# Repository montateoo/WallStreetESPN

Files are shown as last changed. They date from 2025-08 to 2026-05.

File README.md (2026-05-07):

# WallStreetESPN

A compact, self-contained stock market display built on the ESP8266. It fetches real-time prices from the Finnhub API, cycles through your personal portfolio on a 128x64 OLED, and runs a paper trading algorithm in the background — all manageable from a built-in web interface.

---

## Features

- Real-time stock quotes (Finnhub API, free tier)
- Smooth horizontal slide animations between stocks
- Market countdown — shows time until NYSE opens or closes
- Paper trading — SMA(3)/SMA(7) crossover algorithm with $100 virtual budget
- Built-in web UI — add/remove stocks, configure settings, view trading dashboard
- PWM-controlled LED brightness (green = price up / red = price down)
- Persistent storage — portfolio, API key, settings and trading state survive reboots
- NTP time sync (CET/CEST automatic)

---

## Hardware

| Component | Details |
|---|---|
| Microcontroller | ESP8266 (NodeMCU / Wemos D1 Mini) |
| Display | 128x64 OLED I2C (SSD1306, address 0x3C) |
| Green LED | GPIO 13 (D7) + 220Ω resistor |
| Red LED | GPIO 15 (D8) + 220Ω resistor |
| Button — Mode | GPIO 14 (D5) + 10kΩ pull-down |
| Button — WiFi Reset | GPIO 12 (D6) + 10kΩ pull-down |
| I2C SDA | GPIO 4 (D2) |
| I2C SCL | GPIO 5 (D1) |
| Power | USB-C 4.5–9V module |

See `Schematic_wallStreetDisplay_2025-08-30.pdf` for the full circuit diagram.  
3D-printable enclosure parts are in `3DprintComponents/`.

---

## Software Dependencies

Install all of these through **Arduino IDE → Sketch → Include Library → Manage Libraries**:

| Library | Author |
|---|---|
| ArduinoJson | Benoit Blanchon |
| WiFiManager | tzapu |
| Adafruit SSD1306 | Adafruit |
| Adafruit GFX Library | Adafruit |

Board package (via Boards Manager):  
`https://arduino.esp8266.com/stable/package_esp8266com_index.json`  
→ Install **esp8266 by ESP8266 Community**

---

## Setup

### 1. Get a Finnhub API key
Sign up for free at [finnhub.io](https://finnhub.io) and copy your API key.

### 2. Flash the firmware
- Open `code.ino` in Arduino IDE
- Select **Tools → Board → ESP8266 Boards → NodeMCU 1.0**
- Select the correct **Tools → Port** (use Device Manager to find it)
- Upload speed: 115200
- Serial monitor baud rate: **115200**
- Click Upload

### 3. First boot — connect to WiFi
On first boot the device creates a WiFi access point:
- SSID: `WallStreetDisplay`
- Password: `12345678`

Connect to it, enter your home WiFi credentials, and the device will reboot and connect.  
To reset WiFi credentials later: hold the WiFi Reset button for 5 seconds.

### 4. Configure via web UI
With the device connected to your network, press the **Mode button** to enter Server Mode. The OLED shows the IP address. Open it in a browser and:

- Add stock symbols (e.g. `AAPL`, `TSLA`, `MSFT`)
- Enter your Finnhub API key in Settings
- Set the display interval per stock
- Adjust LED brightness (green and red independently)
- Toggle the paper trading algorithm on/off

Press the Mode button again to return to Display Mode.

---

## Display Cycle

In Display Mode the screen cycles through:

```
Stock 1 → Stock 2 → ... → Stock N → Market Countdown → Trading Status → Stock 1 → ...
```

**Stock screen** — symbol, current price ($), daily change (%)  
**Market Countdown** — OPENS / CLOSES with hours and minutes remaining  
**Trading Status** — portfolio value, last trade, total P&L% (shown only when trading is enabled)

---

## Web Interface

| URL | Description |
|---|---|
| `http://<device-ip>/` | Portfolio management |
| `http://<device-ip>/trading` | Paper trading dashboard |
| `http://<device-ip>/add?value=AAPL` | Add a stock |
| `http://<device-ip>/remove?value=AAPL` | Remove a stock |
| `http://<device-ip>/clear` | Remove all stocks |
| `http://<device-ip>/setkey?key=...` | Set API key |
| `http://<device-ip>/settime?time=5` | Set display interval (seconds) |
| `http://<device-ip>/setledgreen?val=80` | Set green LED brightness (0–100) |
| `http://<device-ip>/setledred?val=80` | Set red LED brightness (0–100) |
| `http://<device-ip>/toggletrading` | Toggle trading algorithm on/off |

---

## Paper Trading Algorithm

The device paper-trades your portfolio stocks with a virtual $100 starting budget.

**Algorithm:** SMA(3) / SMA(7) crossover  
- Prices are sampled every 10 minutes (each API fetch cycle)  
- After 7 samples a signal is available  
- **Golden cross** (SMA3 crosses above SMA7) → BUY up to 35% of portfolio value  
- **Death cross** (SMA3 crosses below SMA7) → SELL full position  
- Only trades during NYSE market hours (15:30–22:00 CET)  
- State (cash, positions, trade log) persists in LittleFS as `/trading.json`

Trading can be enabled/disabled from the Settings panel without reflashing.

---

## Storage Layout

| Storage | Key | Content |
|---|---|---|
| LittleFS | `/list.txt` | Stock symbols (one per line) |
| LittleFS | `/trading.json` | Cash balance, open positions, realized P&L |
| EEPROM 0–100 | — | Finnhub API key |
| EEPROM 101–104 | — | Display interval (ms) |
| EEPROM 105 | — | Green LED brightness (0–100) |
| EEPROM 106 | — | Red LED brightness (0–100) |
| EEPROM 107 | — | Trading enabled (0/1) |

---

## Secrets

API keys and credentials are stored in `secrets.toml` (git-ignored):

```toml
[api]
finnhub_key = "your_key_here"
```

This file is for reference only — the key is configured on the device via the web UI and stored in EEPROM.

---

## LED Behaviour

| State | Green LED | Red LED |
|---|---|---|
| Stock price up | ON | OFF |
| Stock price down | OFF | ON |
| Market open (countdown) | Blinking | OFF |
| Market closed (countdown) | OFF | Blinking |
| Server Mode | Alternating | Alternating |

Brightness is independently configurable (0–100%) via PWM.

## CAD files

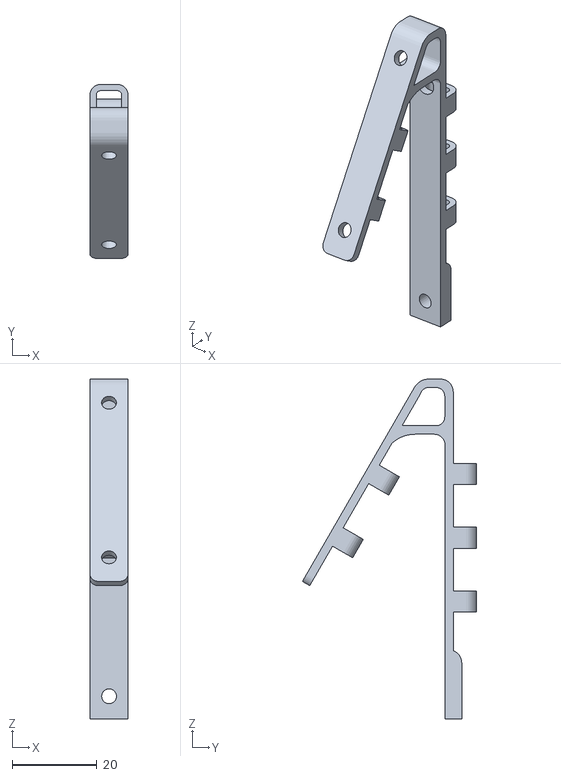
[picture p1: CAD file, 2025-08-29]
3DprintComponents/SupportRight.stl
9.00 x 41.0 x 80.0

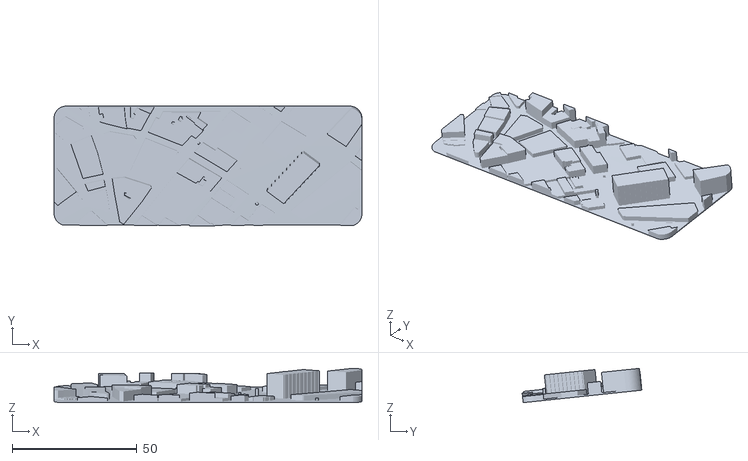
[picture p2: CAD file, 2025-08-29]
3DprintComponents/WallStreetMapSmall.stl
123.4 x 48.0 x 13.7

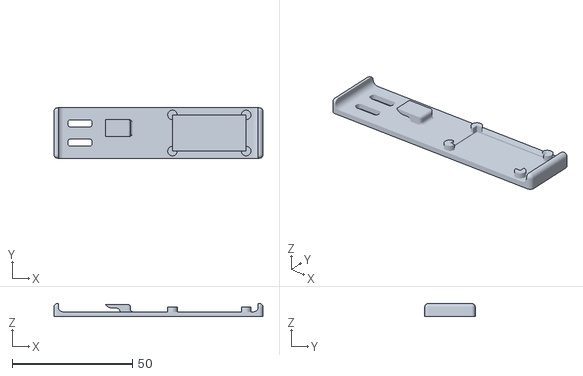
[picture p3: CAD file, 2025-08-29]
3DprintComponents/BasePannel.stl
86.8 x 21.0 x 5.50

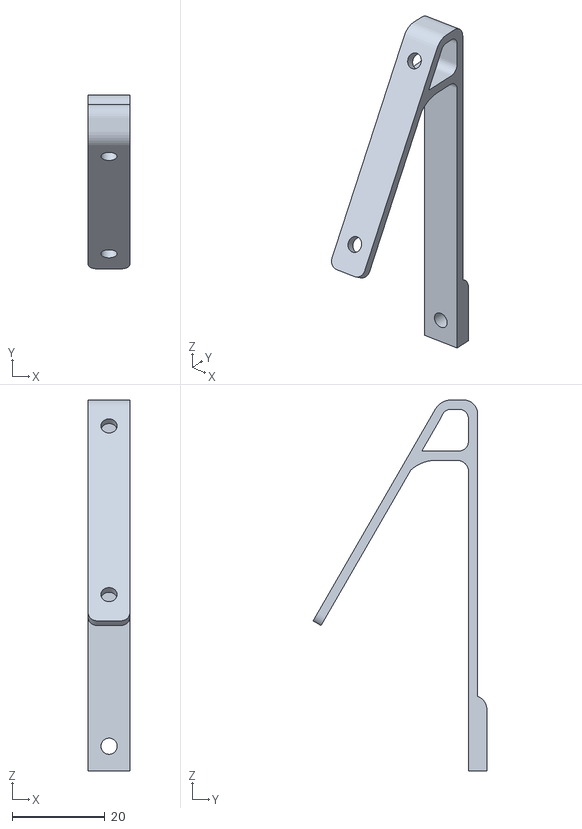
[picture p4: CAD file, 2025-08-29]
3DprintComponents/SupportLeft.stl
9.00 x 37.5 x 80.0

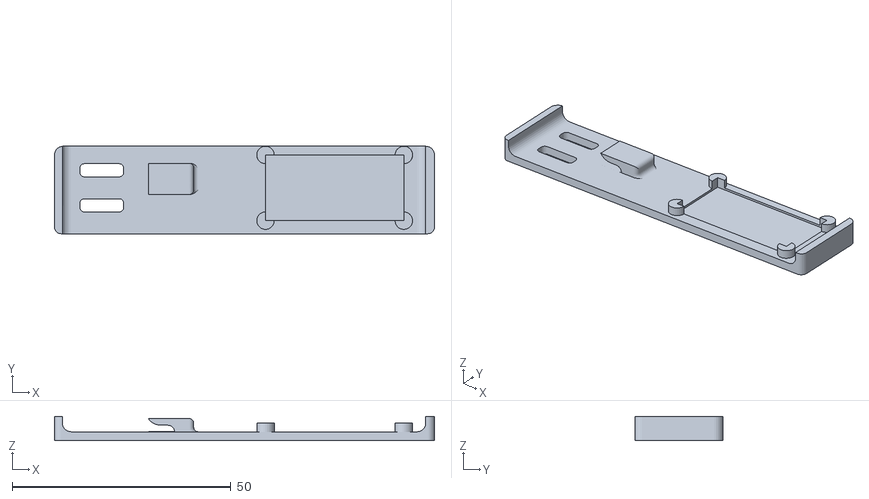
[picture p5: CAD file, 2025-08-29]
3DprintComponents/BottomPannel.stl
86.8 x 20.0 x 5.50

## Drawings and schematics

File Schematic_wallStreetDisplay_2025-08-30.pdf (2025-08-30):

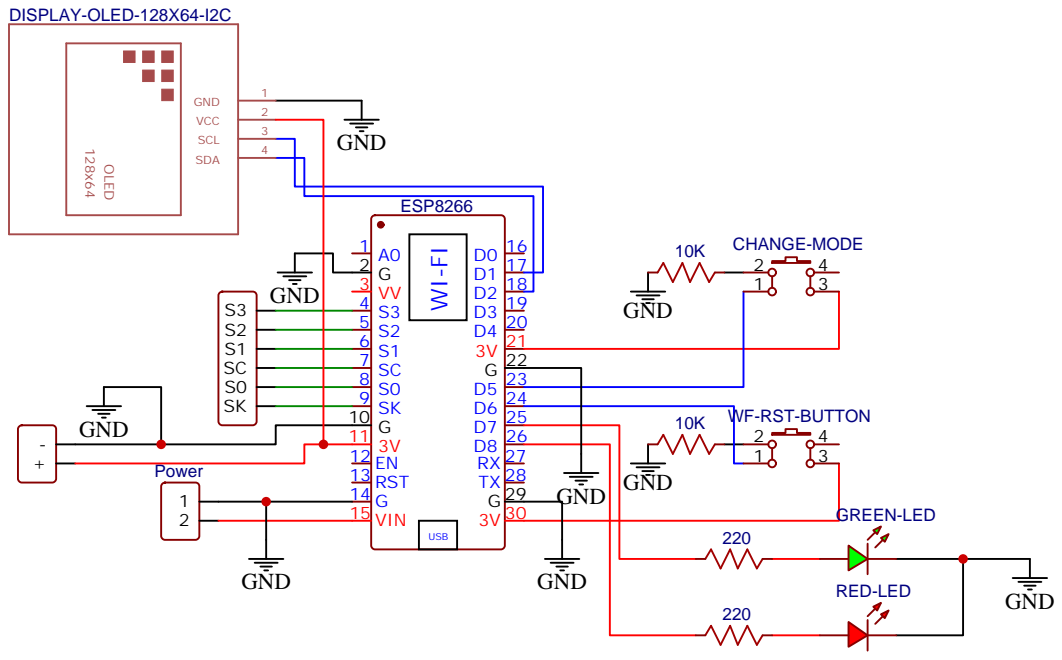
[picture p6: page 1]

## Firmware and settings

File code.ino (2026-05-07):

#include <ESP8266WiFi.h>
#include <ESP8266WebServer.h>
#include <ESP8266HTTPClient.h>
#include <WiFiClientSecure.h>
#include <LittleFS.h>
#include <WiFiManager.h>
#include <ArduinoJson.h>
#include <map>
#include <Wire.h>
#include <EEPROM.h>
#include <Adafruit_GFX.h>
#include <Adafruit_SSD1306.h>
#include <Fonts/FreeSansBold9pt7b.h>
#include <Fonts/FreeSansBold12pt7b.h>
#include <Fonts/FreeSans9pt7b.h>
#include <Fonts/Org_01.h>

// Reserve memory: 0..100 for API key, 101..104 for displayInterval
#define EEPROM_SIZE 200
#define EEPROM_APIKEY_ADDR 0
#define EEPROM_DISPLAY_ADDR 101
#define EEPROM_LED_GREEN_ADDR 105
#define EEPROM_LED_RED_ADDR   106
#define EEPROM_TRADING_EN_ADDR 107

// I2C pins for ESP8266 (D1 = SCL, D2 = SDA)
#define SCREEN_WIDTH 128 // OLED width, in pixels
#define SCREEN_HEIGHT 64 // OLED height, in pixels
#define OLED_RESET -1 // No reset pin
Adafruit_SSD1306 display(SCREEN_WIDTH, SCREEN_HEIGHT, &Wire, OLED_RESET);
uint8_t virtualBuffer[2048]; // 256 x 64 bits

// === linked list Structure ===
struct Node {
  String data;
  Node* next;
};

struct StockData {
  float currentPrice = 0;
  float percent = 0;
};

struct tm timeinfo;

enum DisplayState {
    SHOW_STOCK,
    TRANSITION_TO_COUNTDOWN,
    SHOW_COUNTDOWN,
    TRANSITION_TO_TRADING,
    SHOW_TRADING,
    TRANSITION_TO_STOCK
};

//get the API key on https://finnhub.io/
String apiKey = "";
String ServerAdr = "";

static DisplayState displayState = SHOW_STOCK;
static unsigned long stateStartTime = 0;
static String oldSymbol = "";
static StockData oldData;
static bool firstRun = true;

std::map<String, StockData> stockCache;

Node* head = nullptr;

Node* currentNode = nullptr;
unsigned long lastQuoteRequestTime = 0;
const unsigned long quoteDelay = 3000;
bool isFetching = false;
WiFiClientSecure wifiSecureClient;

const int wifiResetButtonPin = 12;
const int buttonPin = 14;
const int ledGreenPin = 13;
const int ledRedPin = 15;
bool serverMode = false;
int stockNum = 0;

Node* displayNode = nullptr;
unsigned long lastDisplaySwitch = 0;
unsigned long displayInterval = 0; //DEFAULT ITS 5 SECONDS
bool newStock = false;

// === Trading System ===
#define PRICE_HISTORY_LEN 10
#define SMA_SHORT_PERIOD  3
#define SMA_LONG_PERIOD   7
#define STARTING_CASH     100.0f
#define MAX_POSITION_PCT  0.35f

struct TradingPosition {
    float shares       = 0;
    float avgBuyPrice  = 0;
    float priceHistory[PRICE_HISTORY_LEN] = {};
    int   historyCount = 0;
    int   historyHead  = 0;
    bool  prevBullish  = false;
    bool  prevSet      = false;
};

struct TradeRecord {
    String symbol;
    String action;
    float  price;
    float  shares;
    float  pnl;
};

float tradingCash      = STARTING_CASH;
float totalRealizedPnL = 0;
int   ledGreenIntensity = 100;
int   ledRedIntensity   = 100;
bool  tradingEnabled    = true;
std::map<String, TradingPosition> tradingPositions;
TradeRecord tradeLog[5];
int tradeLogHead  = 0;
int tradeLogCount = 0;

//market hours (NY Stock Exchange)
const int MARKET_OPEN_HOUR = 15;
const int MARKET_OPEN_MINUTE = 30;
const int MARKET_CLOSE_HOUR = 22;
const int MARKET_CLOSE_MINUTE = 0;

String prevStatus = "";
String prevCountdown = "";

// NTP servers
const char* ntpServer = "pool.ntp.org";
const long  gmtOffset_sec = 3600;   // CET is UTC+1
const int   daylightOffset_sec = 3600; // +1 hour for CEST (DST)


//24x24 server icon bitmap
const unsigned char PROGMEM serverIcon[] = {
  0x00, 0x00, 0x00, 0x00, 0x00, 0x00, 0x1f, 0xff, 0xf8, 0x3f, 0xff, 0xfc, 0x30, 0x00, 0x0c, 0x37, 
	0xc3, 0x6c, 0x37, 0xc3, 0x6c, 0x30, 0x00, 0x0c, 0x3f, 0xff, 0xfc, 0x3f, 0xff, 0xfc, 0x30, 0x00, 
	0x0c, 0x37, 0xc3, 0x6c, 0x37, 0xc3, 0x6c, 0x30, 0x00, 0x0c, 0x3f, 0xff, 0xfc, 0x3f, 0xff, 0xfc, 
	0x30, 0x00, 0x0c, 0x37, 0xc3, 0x6c, 0x37, 0xc3, 0x6c, 0x30, 0x00, 0x0c, 0x3f, 0xff, 0xfc, 0x1f, 
	0xff, 0xf8, 0x00, 0x00, 0x00, 0x00, 0x00, 0x00
};

//24x24 stock market icon bitmap
const unsigned char PROGMEM dollarIcon[] = {
0x00, 0x00, 0x00, 0x00, 0x7e, 0x00, 0x03, 0xff, 0xc0, 0x07, 0xff, 0xe0, 0x0f, 0xff, 0xf0, 0x1f, 
	0xe7, 0xf8, 0x1f, 0xc3, 0xf8, 0x3f, 0x81, 0xfc, 0x3f, 0x1c, 0xfc, 0x7f, 0x1f, 0xfe, 0x7f, 0x8f, 
	0xfe, 0x7f, 0xc3, 0xfe, 0x7f, 0xe1, 0xfe, 0x7f, 0xf8, 0xfe, 0x7f, 0xfc, 0xfe, 0x3f, 0x1c, 0xfc, 
	0x3f, 0x81, 0xfc, 0x1f, 0xc3, 0xf8, 0x1f, 0xe7, 0xf8, 0x0f, 0xff, 0xf0, 0x07, 0xff, 0xe0, 0x01, 
	0xff, 0x80, 0x00, 0x7e, 0x00, 0x00, 0x00, 0x00
};

// 32x32 wifi icon bitmap
const unsigned char PROGMEM wifiDraw[] = {
	0x00, 0x00, 0x00, 0x00, 0x00, 0x00, 0x00, 0x00, 0x00, 0x00, 0x00, 0x00, 0x00, 0x00, 0x00, 0x00, 
	0x00, 0x00, 0x00, 0x00, 0x00, 0x00, 0x00, 0x00, 0x00, 0x00, 0x00, 0x00, 0x00, 0x00, 0x00, 0x00, 
	0x00, 0x00, 0x00, 0x00, 0x00, 0x00, 0x00, 0x00, 0x00, 0x00, 0x00, 0x00, 0x00, 0x00, 0x00, 0x00, 
	0x00, 0x00, 0x00, 0x00, 0x00, 0x00, 0x00, 0x00, 0x00, 0x00, 0x00, 0x00, 0x00, 0x00, 0x00, 0x00, 
	0x00, 0x00, 0x00, 0x00, 0x00, 0x00, 0x00, 0x00, 0x00, 0x00, 0x00, 0x3f, 0xe0, 0x00, 0x00, 0x00, 
	0x00, 0x00, 0x03, 0xff, 0xff, 0xc0, 0x00, 0x00, 0x00, 0x00, 0x1f, 0xff, 0xff, 0xf8, 0x00, 0x00, 
	0x00, 0x00, 0xff, 0xff, 0xff, 0xff, 0x00, 0x00, 0x00, 0x03, 0xff, 0xff, 0xff, 0xff, 0xc0, 0x00, 
	0x00, 0x0f, 0xff, 0xff, 0xff, 0xff, 0xf0, 0x00, 0x00, 0x1f, 0xff, 0xff, 0xff, 0xff, 0xf8, 0x00, 
	0x00, 0x7f, 0xff, 0x00, 0x00, 0xff, 0xfe, 0x00, 0x00, 0xff, 0xf8, 0x00, 0x00, 0x1f, 0xff, 0x00, 
	0x01, 0xff, 0xe0, 0x00, 0x00, 0x07, 0xff, 0x80, 0x03, 0xff, 0x00, 0x00, 0x00, 0x00, 0xff, 0xc0, 
	0x07, 0xfc, 0x00, 0x00, 0x00, 0x00, 0x7f, 0xe0, 0x07, 0xf8, 0x00, 0xff, 0xff, 0x00, 0x1f, 0xe0, 
	0x07, 0xf0, 0x07, 0xff, 0xff, 0xe0, 0x0f, 0xe0, 0x07, 0xe0, 0x3f, 0xff, 0xff, 0xfc, 0x07, 0xe0, 
	0x03, 0xc0, 0x7f, 0xff, 0xff, 0xfe, 0x03, 0xc0, 0x00, 0x01, 0xff, 0xff, 0xff, 0xff, 0x80, 0x00, 
	0x00, 0x03, 0xff, 0xff, 0xff, 0xff, 0xc0, 0x00, 0x00, 0x0f, 0xff, 0xc0, 0x07, 0xff, 0xf0, 0x00, 
	0x00, 0x0f, 0xfe, 0x00, 0x00, 0x3f, 0xf0, 0x00, 0x00, 0x1f, 0xf8, 0x00, 0x00, 0x1f, 0xf8, 0x00, 
	0x00, 0x1f, 0xe0, 0x00, 0x00, 0x07, 0xf8, 0x00, 0x00, 0x1f, 0xc0, 0x00, 0x00, 0x03, 0xf8, 0x00, 
	0x00, 0x0f, 0x00, 0x0f, 0xf8, 0x00, 0xe0, 0x00, 0x00, 0x00, 0x00, 0x7f, 0xff, 0x00, 0x00, 0x00, 
	0x00, 0x00, 0x03, 0xff, 0xff, 0xc0, 0x00, 0x00, 0x00, 0x00, 0x07, 0xff, 0xff, 0xe0, 0x00, 0x00, 
	0x00, 0x00, 0x0f, 0xff, 0xff, 0xf0, 0x00, 0x00, 0x00, 0x00, 0x1f, 0xff, 0xff, 0xf8, 0x00, 0x00, 
	0x00, 0x00, 0x1f, 0xff, 0xff, 0xf8, 0x00, 0x00, 0x00, 0x00, 0x1f, 0xe0, 0x03, 0xf8, 0x00, 0x00, 
	0x00, 0x00, 0x0f, 0x80, 0x01, 0xf0, 0x00, 0x00, 0x00, 0x00, 0x06, 0x00, 0x00, 0x60, 0x00, 0x00, 
	0x00, 0x00, 0x00, 0x00, 0x00, 0x00, 0x00, 0x00, 0x00, 0x00, 0x00, 0x07, 0xe0, 0x00, 0x00, 0x00, 
	0x00, 0x00, 0x00, 0x1f, 0xf8, 0x00, 0x00, 0x00, 0x00, 0x00, 0x00, 0x1f, 0xf8, 0x00, 0x00, 0x00, 
	0x00, 0x00, 0x00, 0x3f, 0xfc, 0x00, 0x00, 0x00, 0x00, 0x00, 0x00, 0x3f, 0xfc, 0x00, 0x00, 0x00, 
	0x00, 0x00, 0x00, 0x3f, 0xfc, 0x00, 0x00, 0x00, 0x00, 0x00, 0x00, 0x3f, 0xfc, 0x00, 0x00, 0x00, 
	0x00, 0x00, 0x00, 0x3f, 0xfc, 0x00, 0x00, 0x00, 0x00, 0x00, 0x00, 0x3f, 0xfc, 0x00, 0x00, 0x00, 
	0x00, 0x00, 0x00, 0x1f, 0xf8, 0x00, 0x00, 0x00, 0x00, 0x00, 0x00, 0x0f, 0xf0, 0x00, 0x00, 0x00, 
	0x00, 0x00, 0x00, 0x07, 0xe0, 0x00, 0x00, 0x00, 0x00, 0x00, 0x00, 0x00, 0x00, 0x00, 0x00, 0x00, 
	0x00, 0x00, 0x00, 0x00, 0x00, 0x00, 0x00, 0x00, 0x00, 0x00, 0x00, 0x00, 0x00, 0x00, 0x00, 0x00, 
	0x00, 0x00, 0x00, 0x00, 0x00, 0x00, 0x00, 0x00, 0x00, 0x00, 0x00, 0x00, 0x00, 0x00, 0x00, 0x00, 
	0x00, 0x00, 0x00, 0x00, 0x00, 0x00, 0x00, 0x00, 0x00, 0x00, 0x00, 0x00, 0x00, 0x00, 0x00, 0x00, 
	0x00, 0x00, 0x00, 0x00, 0x00, 0x00, 0x00, 0x00, 0x00, 0x00, 0x00, 0x00, 0x00, 0x00, 0x00, 0x00
};

ESP8266WebServer server(80);

void drawStockFrame(String symbol, StockData data, int xOffset);
void updateLEDs(StockData data);

bool ledGreenState = false;
bool ledRedState   = false;

uint16_t ledGammaPWM(int intensity) {
    if (intensity <= 0)   return 0;
    if (intensity >= 100) return 1023;
    float norm = intensity / 100.0f;
    return (uint16_t)(pow(norm, 2.2f) * 1023.0f + 0.5f);
}

void setLedGreen(bool on) {
    ledGreenState = on;
    analogWrite(ledGreenPin, on ? ledGammaPWM(ledGreenIntensity) : 0);
}
void setLedRed(bool on) {
    ledRedState = on;
    analogWrite(ledRedPin, on ? ledGammaPWM(ledRedIntensity) : 0);
}

void addNode(String value) {
  if (value == "") return;
  Node* newNode = new Node{value, nullptr};
  if (!head) head = newNode;
  else {
    Node* temp = head;
    while (temp->next) temp = temp->next;
    temp->next = newNode;
  }
  saveListToFS();
  stockNum++;
  newStock = true;
}

bool removeNode(String value) {
  Node* temp = head;
  Node* prev = nullptr;
  while (temp) {
    if (temp->data == value) {
      if (prev) prev->next = temp->next;
      else head = temp->next;
      delete temp;
      saveListToFS();
      stockNum--;
      return true;
    }
    prev = temp;
    temp = temp->next;
  }
  return false;
}

void clearList() {
  while (head) {
    Node* temp = head;
    head = head->next;
    delete temp;
  }
  saveListToFS();
  stockNum=0;

  currentNode = nullptr;
  isFetching = false;
}

String listToStringHTML() {
  String output = "<ul>";
  Node* temp = head;
  while (temp) {
    output += "<li>" + temp->data + "</li>";
    temp = temp->next;
  }
  output += "</ul>";
  return output;
}

void saveListToFS() {
  File file = LittleFS.open("/list.txt", "w");
  if (!file) {
    Serial.println("Errore apertura file per scrittura!");
    return;
  }
  Node* temp = head;
  while (temp) {
    file.println(temp->data);
    temp = temp->next;
  }
  file.close();
}

void freeListOnly() {
  while (head) {
    Node* temp = head;
    head = head->next;
    delete temp;
  }
  stockNum = 0;
  currentNode = nullptr;
  isFetching = false;
}


void loadListFromFS() {
  if (!LittleFS.exists("/list.txt")) {
    Serial.println("⚠️ list.txt non trovato");
    return;
  }

  File file = LittleFS.open("/list.txt", "r");
  if (!file) {
    Serial.println("⚠️ Impossibile aprire list.txt in lettura");
    return;
  }

  Node* tempHead = nullptr;
  Node* tail = nullptr;
  int count = 0;

  while (file.available()) {
    String line = file.readStringUntil('\n');
    line.trim();
    if (line.length() > 0) {
      Node* newNode = new Node{line, nullptr};
      if (!tempHead) {
        tempHead = newNode;
        tail = newNode;
      } else {
        tail->next = newNode;
        tail = newNode;
      }
      count++;
    }
  }
  file.close();

  if (tempHead) {
    freeListOnly();
    head = tempHead;
    stockNum = count;
    Serial.println("✅ Lista caricata da LittleFS");
  } else {
    Serial.println("⚠️ File vuoto o nessun dato valido");
  }
}

// WEB SERVER
void handleRoot() {
  String html = R"rawliteral(
<!DOCTYPE html>
<html>
<head>
  <title>WallStreetDisplay</title>
  <style>
    body {
      font-family: Arial, sans-serif;
      background-color: #f2f2f2;
      display: flex;
      justify-content: center;
      align-items: center;
      height: 100vh;
      margin: 0;
    }
    .container {
      background-color: #fff;
      padding: 30px;
      border-radius: 12px;
      box-shadow: 0 4px 8px rgba(0,0,0,0.1);
      text-align: center;
      max-width: 500px;
      width: 100%;
    }
    h1 {
      color: #333;
      font-size: 28px;
    }
    .form-row {
      margin: 10px 0;
    }
    form {
      display: flex;
    }
    .text-input {
      padding: 10px;
      font-size: 16px;
      border: 1px solid #ccc;
      border-radius: 4px 0 0 4px;
      flex: 1;
    }
    .blue-button {
      padding: 10px 20px;
      font-size: 16px;
      background-color: #2196F3;
      color: white;
      border: none;
      border-radius: 0 4px 4px 0;
      cursor: pointer;
    }
    .blue-button:hover {
      background-color: #0b7dda;
    }
    .red-button {
      padding: 10px 20px;
      background-color: #f44336;
      color: white;
      border: none;
      border-radius: 6px;
      cursor: pointer;
      margin-top: 15px;
    }
    .red-button:hover {
      background-color: #d32f2f;
    }
    .green-button {
      padding: 10px 20px;
      background-color: #4CAF50;
      color: white;
      border: none;
      border-radius: 6px;
      cursor: pointer;
      margin-top: 15px;
    }
    .green-button:hover {
      background-color: #3e8e41;
    }
    .settings-button {
      margin-top: 20px;
      background-color: #4CAF50;
      border: none;
      color: white;
      padding: 10px 20px;
      border-radius: 6px;
      cursor: pointer;
    }
    .settings-button:hover {
      background-color: #3e8e41;
    }
    #settingsPanel {
      display: none;
      margin-top: 15px;
      padding: 15px;
      border: 1px solid #ccc;
      border-radius: 8px;
      background: #fafafa;
    }
    ul {
      text-align: left;
      margin-top: 20px;
      padding-left: 20px;
    }
    li {
      background: #eee;
      margin: 4px 0;
      padding: 6px;
      border-radius: 4px;
    }
    #confirmModal {
      display: none;
      position: fixed;
      top: 0;
      left: 0;
      width: 100%;
      height: 100%;
      background: rgba(0,0,0,0.5);
      text-align: center;
    }
    .modal-content {
      background: white;
      margin: 15% auto;
      padding: 20px;
      border-radius: 8px;
      width: 300px;
    }
  </style>
  <script>
    function showCustomConfirm() {
      document.getElementById("confirmModal").style.display = "block";
    }
    function hideCustomConfirm() {
      document.getElementById("confirmModal").style.display = "none";
    }
    function proceedClear() {
      window.location.href = "/clear";
    }
    function toggleSettings() {
      const panel = document.getElementById("settingsPanel");
      panel.style.display = (panel.style.display === "none" ? "block" : "none");
    }
    function showSavedPopup() {
      const popup = document.getElementById("savedPopup");
      popup.style.display = "block";
      setTimeout(() => { popup.style.display = "none"; }, 2000);
    }
    function showErrorPopup() {
      const popup = document.getElementById("errorPopup");
      popup.style.display = "block";
      setTimeout(() => { popup.style.display = "none"; }, 2000);
    }
    window.addEventListener('DOMContentLoaded', () => {
      const params = new URLSearchParams(window.location.search);
        if (params.get("saved") === "1") {
          showSavedPopup();
          window.history.replaceState({}, document.title, window.location.pathname);
        } else if (params.get("saved") === "2") {
          showErrorPopup();
          window.history.replaceState({}, document.title, window.location.pathname);
        }
    });

  </script>
</head>
<body>
  <div class="container">
    <h1>WallStreetDisplay</h1>

    <div class="form-row">
      <form action='/add'>
        <input type='text' name='value' placeholder='Add new stock' class='text-input'>
        <button type='submit' class='blue-button'>Add</button>
      </form>
    </div>

    <div class="form-row">
      <form action='/remove'>
        <input type='text' name='value' placeholder='Remove stock' class='text-input'>
        <button type='submit' class='blue-button'>Remove</button>
      </form>
    </div>

    <button class='red-button' onclick='showCustomConfirm()'>Erase all</button>

    <h3>My stocks:</h3>
)rawliteral";

  html += listToStringHTML();

  extern String apiKey;
  html += R"rawliteral(
    <button class='settings-button' onclick='toggleSettings()'>Settings</button>
    <br><a href='/trading'><button class='green-button' style='margin-top:10px'>Trading Dashboard</button></a>
    <div id="settingsPanel">
      <h3>API Key</h3>
      <form action='/setkey?saved=1'>
        <input type='text' name='key' value=')rawliteral" + apiKey + R"rawliteral(' class='text-input'>
        <button type='submit' class='blue-button'>Save</button>
      </form>

      <h3>Display Time per Stock</h3>
      <form action='/settime'>
        <input type='number' name='time' min='0' value=')rawliteral" + String(displayInterval/1000) + R"rawliteral(' class='text-input'>
        <button type='submit' class='blue-button'>Save</button>
      </form>

      <h3>LED Brightness</h3>
      <label>Green: <span id='gv'>)rawliteral" + String(ledGreenIntensity) + R"rawliteral(</span>%</label>
      <form action='/setledgreen' style='margin-top:4px'>
        <input type='range' name='val' min='0' max='100' value=')rawliteral" + String(ledGreenIntensity) + R"rawliteral('
          oninput="document.getElementById('gv').textContent=this.value"
          style='flex:1;border:none;padding:6px'>
        <button type='submit' class='blue-button'>Save</button>
      </form>
      <label>Red: <span id='rv'>)rawliteral" + String(ledRedIntensity) + R"rawliteral(</span>%</label>
      <form action='/setledred' style='margin-top:4px'>
        <input type='range' name='val' min='0' max='100' value=')rawliteral" + String(ledRedIntensity) + R"rawliteral('
          oninput="document.getElementById('rv').textContent=this.value"
          style='flex:1;border:none;padding:6px'>
        <button type='submit' class='blue-button'>Save</button>
      </form>

      <h3>Trading Mode</h3>
    )rawliteral";
  html += "<a href='/toggletrading' style='text-decoration:none'>";
  html += "<button class='";
  html += tradingEnabled ? "green-button" : "red-button";
  html += "'>Trading: ";
  html += tradingEnabled ? "ON" : "OFF";
  html += "</button></a>";
  html += R"rawliteral(
    </div>
  )rawliteral";

  html += R"rawliteral(
  </div>

  <!-- Custom Confirm Modal -->
  <div id="confirmModal">
    <div class="modal-content">
      <h3>Are you sure?</h3>
      <p>This will delete the entire list.</p>
      <button onclick="proceedClear()" class="red-button">Yes, erase</button>
      <button onclick="hideCustomConfirm()" class="green-button">No, go back</button>
    </div>
  </div>

</body>

<div id="savedPopup" class="greenPopup">Changes Saved</div>

<div id="errorPopup" class="redPopup">Invalid Data</div>

<style>
  .greenPopup {
    display: none;
    position: fixed;
    top: 50%;
    left: 50%;
    transform: translate(-50%, -50%);
    background: #4CAF50;
    color: white;
    padding: 30px 50px;
    border-radius: 12px;
    box-shadow: 0 4px 12px rgba(0,0,0,0.4);
    font-size: 20px;
    z-index: 9999;
    text-align: center;
  }

  .redPopup {
    display: none;
    position: fixed;
    top: 50%;
    left: 50%;
    transform: translate(-50%, -50%);
    background: #f44336;
    color: white;
    padding: 30px 50px;
    border-radius: 12px;
    box-shadow: 0 4px 12px rgba(0,0,0,0.4);
    font-size: 20px;
    z-index: 9999;
    text-align: center;
  }

</style>

</html>
)rawliteral";

  server.send(200, "text/html", html);
}

void handleSetKey() {
  if (server.hasArg("key")) {
    apiKey = server.arg("key");
    saveApiKey(apiKey);
  }
  server.sendHeader("Location", "/?saved=1");
  server.send(303);
}

void saveApiKey(const String &key) {
  int maxLen = 100;
  int len = key.length();
  if (len > maxLen) len = maxLen;

  for (int i = 0; i < len; i++) {
    EEPROM.write(i, key[i]);
  }
  EEPROM.write(len, '\0');
  EEPROM.commit();
}

void loadApiKey() {
  char buf[101];
  for (int i = 0; i < 100; i++) {
    buf[i] = EEPROM.read(i);
    if (buf[i] == '\0') break;
  }
  buf[100] = '\0';
  apiKey = String(buf);
  Serial.println("Loaded API key: " + apiKey);
}

void handleSetTime() {
  if (server.hasArg("time")) {
    int newTime = server.arg("time").toInt();

    int stockCount = stockNum;
    if (stockCount == 0) stockCount = 1; // avoid divide-by-zero

    // Constraint: newTime >= 0 and newTime * stockCount <= 60000
    if (newTime >= 1 && (newTime * stockCount * 1000) <= 600000) {
      displayInterval = newTime*1000;
      saveDisplayInterval(displayInterval);

        server.sendHeader("Location", "/?saved=1");  // redirect
        server.send(303);
    } else {
      //server.send(200, "text/html", "Invalid value. Max allowed: " + String(600 / stockCount) + "s <a href='/'>Back</a>");
      server.sendHeader("Location", "/?saved=2");  // redirect
      server.send(303);
    }
  } else {
    //server.send(200, "text/html", "Missing parameter <a href='/'>Back</a>");
    server.sendHeader("Location", "/?saved=2");  // redirect
    server.send(303);
  }
}
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
void loop() {
  // Handle WiFi reset button (hold >5s to clear credentials)
  static bool wifiResetPressed = false;
  static unsigned long wifiResetStart = 0;

  if (digitalRead(wifiResetButtonPin) == HIGH) {
    if (!wifiResetPressed) {
      wifiResetPressed = true;
      wifiResetStart = millis();
    } else if (millis() - wifiResetStart > 5000) {
      Serial.println("🔧 WiFi reset requested via button");
      setLedGreen(false);
      setLedRed(false);
      delay(500);
      WiFiManager wifiManager;
      wifiManager.resetSettings();
      delay(500);
      ESP.restart();
    }
  } else {
    wifiResetPressed = false;
  }

  if (WiFi.getMode() == WIFI_AP) {
    server.handleClient();
    return;
  }

  checkButton();

  if (serverMode) {
    server.handleClient();
    blinkLedsInServerMode();  
    showServerMode();
  } else {
    display.clearDisplay();

    if (!head) {
      showWallStreet();
      Serial.println("⚠️ No stocks to display. Use SERVER mode to add.");
      delay(4000);
      showFirstStart();
      delay(4000);
      serverMode = true;
      return;
    }

    if (apiKey == "") {
      showInsertAPI();
      return;
    }

    if (!isFetching && (millis() - lastRequest > 600000 || newStock)) {
      currentNode = head;
      isFetching = true;
      lastQuoteRequestTime = millis() - quoteDelay;
      lastRequest = millis();
    }

    if (isFetching) {
      showWallStreet();
      handleNonBlockingFetch();
      if (!isFetching) { runTradingAlgorithm(); saveTradingState(); }
      if (newStock) newStock = false;
    } else {
      updateDisplay();
    }
  }
}
